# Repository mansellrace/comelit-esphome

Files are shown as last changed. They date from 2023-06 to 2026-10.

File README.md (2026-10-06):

# comelit-esphome
Comelit Simplebus Interface for Home Assistant

It works with simplebus 1, simplebus 1 color, simplebus 2.

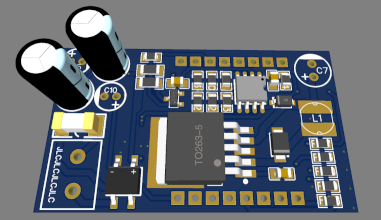
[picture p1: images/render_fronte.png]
render
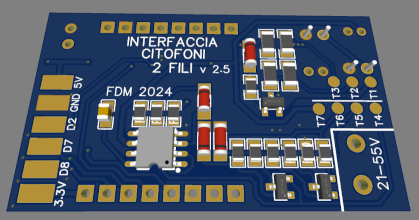
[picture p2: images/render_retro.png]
render2
 

**Side project:** *There is also a side-project that shares the same hardware: [comelit-esp8266](https://github.com/mansellrace/comelit-esp8266). it is a simplified and unrelated version of the home assistant world, created to allow decoding and interfacing the same protocol, with the same hardware, to interface the comelit bus even different home automation systems, to build intercom call repeaters, etc.*

## Introduction to the project
Initially, I wanted to modify my Comelit mini hands-free intercom 6721W to interface it with Home Assistant, so that I can receive a notification when someone intercoms me, and to be able to open the two doors controlled by the intercom conveniently remotely.

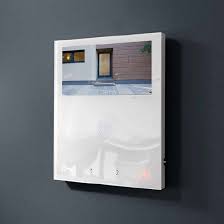
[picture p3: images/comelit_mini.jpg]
Comelit mini


The intercom works on Comelit's proprietary Simplebus2 2-wire bus.

I wanted to connect directly to the printed circuit board of the indoor station, which, however, uses the same speaker for ringing and voice calling, has touch buttons, the situation was getting complicated. I discarded the idea of using a Ring Intercom, because although it works very well and supports the Simplebus2 protocol, it does not allow you to control the opening of the second door, is bulky, works only in the cloud, and has the problem of battery power.

I then discovered the wonderful work of **[plusvic](https://github.com/plusvic/simplebus2-intercom)** who analyzed and decoded the simplebus protocol, and made a ring repeater based on a PIC used to decode the protocol, a wireless transmission chip and ESP8266. 
**[aoihaugen](https://github.com/aoihaugen/simplebus2-intercom)** created a fork, and adapted the code to decode the signal on arduino. I want to give a huge thanks to both of you, without your work I would never have reached my goal, I took abundant cues from both of you for hardware and software.

In my implementation I used a Wemos d1 mini with Esphome-based firmware for easy integration on Home Assistant. Can also interface with [Homey Pro](homey.md)

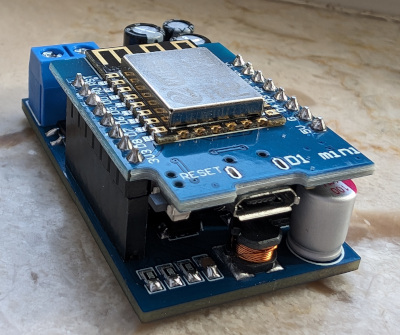
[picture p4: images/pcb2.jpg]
PCB2
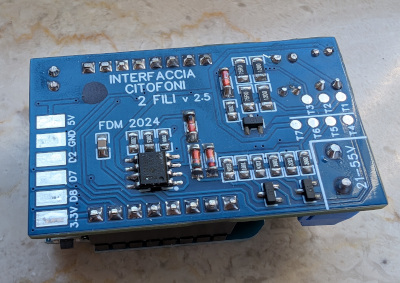
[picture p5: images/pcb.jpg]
PCB
 

The project makes it possible to receive and send commands that pass through the comelit bus, such as calling an internal intercom, opening a door, etc.

It is not possible to receive and send audio and video stream to home assistant.

You can receive a notification when someone sends a call to your internal intercom, and you can open the external door via home assistant.

You can send any command that the indoor intercom or the outdoor intercom generates.

The project supports switching of comelit expansion relays, allows control of multiple gates, separate triggers for call from external intercom or for out-of-door call, etc.

The pcb is powered directly from the bus, and is to be connected directly in parallel with the indoor intercom.

## Purchase materials and pcb

I can supply the printed circuit board, components, or even the entire hardware already soldered and tested.

If you are interested, please contact me at mansellrace@gmail.com

## [Protocol explanation](protocol.md)

## [Hardware and schematics](hardware.md)

## [External component docs](components/README.md)

## First set-up
Prerequisite: Home Assistant.

Boards supplied by me arrive already flashed. If you assembled your own, install the firmware from the [project page](https://mansellrace.github.io/comelit-esphome/) straight from your browser over USB.

- Connect the pcb to the bus. A wifi network called comelit-default will appear. Connect and open the browser, a page will pop up that allows you to set up your wifi network. If it does not open go [here](http://192.168.4.1)
- Home Assistant will discover the device automatically. Add it from the ESPHome integration. Among its entities you will find an **Intercom address** number, an **Incoming call** binary sensor and an **Open Door** button.
- Find your address: go [here](http://comelit-default.local/), where you will find a log of the commands received from the bus. Press a button on your intercom and note the address it generated.
- Set the **Intercom address** number to that address. The **Incoming call** sensor now fires whenever someone calls your intercom. The address is read at runtime, so there is nothing to recompile.
- The **Open Door** button sends command 16, which in most cases already opens the main gate.
- Firmware updates show up on their own as an update entity in Home Assistant. Press "Install" when one appears.
- Have fun!

Besides the binary sensor, every command received on the bus is also fired as a Home Assistant event, which you can use to trigger automations without adding any entity. [More information here](components/README.md#event)

## Doorbell notification on your phone

[@matzZz](https://github.com/matzZz) built a Home Assistant blueprint on top of this project: when someone rings, the phones you choose get a push notification with an **Open door** button.



- The door cannot be opened by accident: the button only shows up on a long press, a locked phone asks for Face ID or to be unlocked first, and the button works only for a limited time after the ring (2 minutes by default). Every ring gets its own button, so an old notification opens nothing.
- As soon as someone opens the door, or the time runs out, the notification disappears from every phone. Optionally, everyone gets a message saying who opened.
- It can notify only the phones that are at home.

It only needs two entities the device already has: choose **Incoming call** as the ring sensor and **Open Door** as the door opener.

Requirements: Home Assistant 2025.4 or later, and the Home Assistant Companion app on the phones. To notify only the phones that are at home, location tracking must be enabled in the app.

You can also install it by hand: copy [comelit_doorbell_door_opener.yaml](blueprints/automation/comelit_doorbell_door_opener.yaml) into the `blueprints/automation/` folder of your Home Assistant configuration.

## Customising your device

The stock firmware covers one intercom address and two doors. If you need more than that (several binary sensors, extra buttons, expansion relays, a different sensitivity), you can **adopt** the device:

- Install the "ESPHome Device Builder" add-on. It will show your device with an **ADOPT** button.
- Adopting copies the whole stock configuration into your dashboard, so every entity is there in front of you, ready to be renamed, removed or added to.
- Full list of options: [external component docs](components/README.md).

> [!IMPORTANT]
> Once you adopt the device, its configuration is yours and the automatic update entity goes away. From that point on you update it by recompiling from the ESPHome Device Builder.

## Commands description

An explanation of the commands that can be found on the bus can be found [here](protocol.md#list-of-commands)

## Updates:
- **2023, June**: First hardware revision and first available software
- **2023, August**: Hw version 2.0, first tests with onboard switching regulator, added pads to easily connect to some external pins
- **2023, September**: Hw version 2.2, added protection circuit for power section. Added dynamic resistor in series with power supply.
- **2023, November**: Hw version 2.4, minor adjustments to power section, added possibility of simultaneous bus and usb connection.
- **2023, November**: Thanks to [@monxas](https://github.com/monxas) for creating a box that can be 3d printed :)
- **2024, January**: Hw version 2.5, added ability to adjust reception sensitivity to two levels
- **2024, February**: Release of the new software. Now the project is based on an external component of esphome and configuration is much easier.
- **2024, August**: Hw version 2.6, added compatibility with simplebus 1 and simplebus 1 color. There is also a hardware revision dedicated to intercom kit systems with 2 wires for bus wires and 2 wires for power.
- **2025, April**: Hw version 2.7 specific for Simplebus 1
- **2025, August**: Software release 2025.08. Home Assistant events now require `homeassistant_services: true` inside the `api` configuration.
- **2026, August**: The address of a binary sensor can be a lambda, so it can be driven from a Home Assistant `number` entity and changed at runtime without recompiling anything.
- **2026, August**: Two new entities report what travels on the bus: a `text_sensor` showing the last command as `C50_A10`, and an `event` entity tied to one address that fires with the command number.
- **2026, August**: Boards now ship pre-flashed and keep themselves up to date. Each release is built and published automatically, a **Firmware** update entity shows the new version in Home Assistant, and the device can be adopted in the ESPHome Device Builder to get the whole configuration for editing. Esphome compiler is no longer required for most installations, and the setup is quicker. Blank boards can be flashed from the browser at the [project page](https://mansellrace.github.io/comelit-esphome/).
- **2026, September**: Thanks to [@matzZz](https://github.com/matzZz) for a Home Assistant blueprint that sends a push notification with an "Open door" button when someone rings. [Details here](#doorbell-notification-on-your-phone)
- **2026, October**: Thanks to Eladio for testing the board with Homey Pro. [Homey Pro quick guide](homey.md)

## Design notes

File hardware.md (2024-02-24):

# Hardware

I adapted the circuit proposed by plusvic by modifying it to fit the situation of my condominium system and the needs of esphome.
The open circuit voltage I detect on the bus wires is about 35V, and the data signal is superimposed on the DC voltage.

The exchange of information (commands) between indoor and outdoor station is through a 25kHz modulated data signal, in my case of peak-to-peak amplitude varying from 0.5V to 5V depending on the distance of the device that is transmitting.
When audio/video communication is initiated, an additional high-frequency signal is added.

render render2

[Schematic here](schematic_2.5.pdf)

## Power supply and filtering

The circuit has the option of being powered directly from the bus.

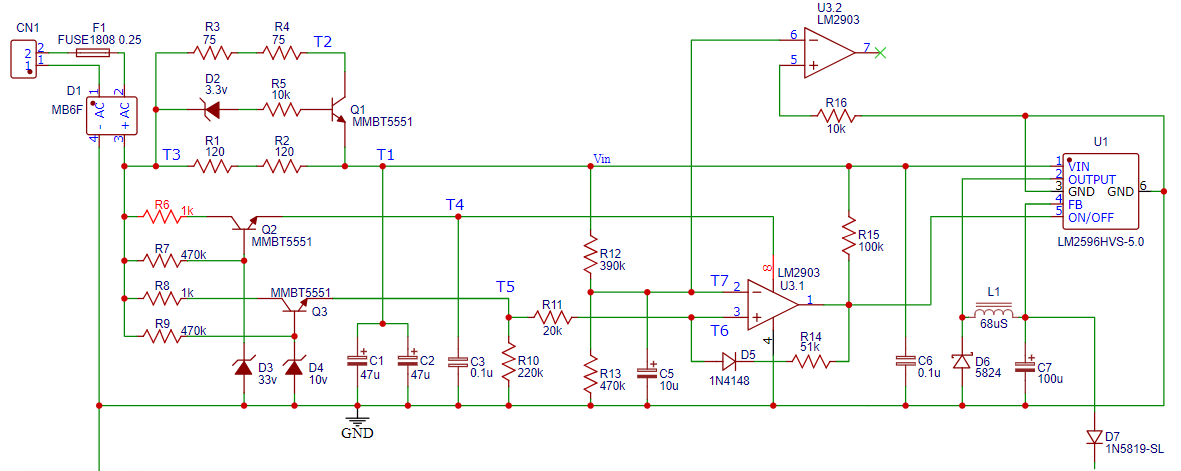
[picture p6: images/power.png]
power


I decided to use a wide-range input switching regulator, LM2596HVS-5.0, which supports up to 60v input and gives 5v output.

The whole circuit draws about 20mA from the bus line, which increases to 160mA during data transmission.

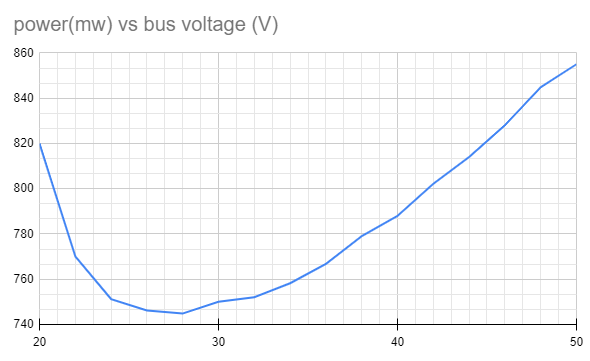
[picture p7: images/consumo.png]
consumo


I placed a 250mA fuse at the input to protect the circuit, followed by a rectifier bridge.

Power for the switching module is taken downstream from an RC low-pass filter, formed by R1, R2, R3, R4, and C1, C2, which eliminates fluctuations due to data transmission. 

Since the circuit must work well over a wide voltage range, the resistor value is "dynamic."
R1 and R2 are directly placed in series with the load.
When the voltage at the ends of R1 and R2 is greater than 2.5v, the resistor branch formed by R3 and R4 is gradually placed in parallel.
This causes the value of the overall resistance to vary linearly from 240Ω to 80Ω, adjusting automatically according to the current flowing through them.

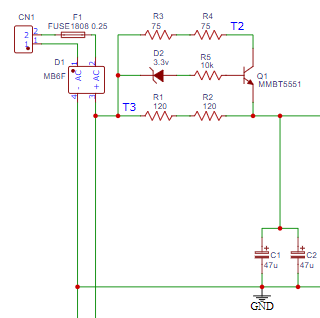
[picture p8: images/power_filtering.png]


### Power supply protection

The bus voltage may vary depending on the system.
Normal values for a video system are about 32-38v.
Some times they operate with voltages around 25v.

The switching regulator suffers from low bus voltages.
When the input voltage decreases, it requires more current from the bus to compensate.
But requiring more current generates more drop on the filter resistors, so the input voltage to the switching drops and the system collapses.
With wemos consumption, the situation becomes unstable below 18v from the bus.
 
In some intercom systems, after a power failure, the power supply slowly switches the bus on, so sometimes the voltage can be below 18v.
To protect the circuit, I added a protection stage that enables the switching regulator only under certain conditions.

The heart of this circuit is a comparator made with LM2903. It compares the voltage across the capacitors that feeding the switching ic with a reference obtained with zener stabilization. There is also a hysteresis. The circuit enables the switching ic when the input voltage is at least 20.5v and when it is stable for a few seconds.
After enabling it, the turn-off threshold is lowered by D5, R14 to about 18v.
In this way, the circuit never becomes unstable.

If the system works with low voltages (around 21-22v), more stability can be achieved by shorting R1.
In this case the shutdown threshold is lowered by a couple of volts and the system remains stable.

## Data receiving section

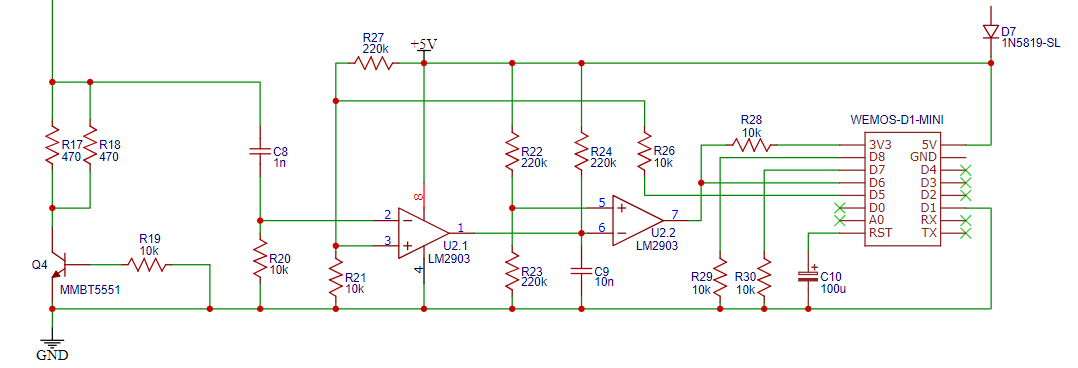
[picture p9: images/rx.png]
rx


As in the circuit I was inspired by, the data signal is picked up from the bus by a high-pass type filter, in the schematic consisting of R20 and C8, 10kΩ and 1nF, respectively.

The filter has a cutoff frequency of about 15kHz, sufficient to reduce interference due to baseband audio communication.

The signal at the ends of the resistor is then given as input to a dual LM2903 comparator with an open collector type output.

The threshold against which the signal is compared is variable, depending on how output D5 is set.
In this way the input sensitivity can be adjusted to two levels according to the plant situation; sometimes the bus may receive interference.

To simplify signal reception by the Wemos, I decided to insert a monostable stage, eliminating the 25-kHz carrier and taking advantage of the second comparator already on board the LM2903.

In the presence of a signal, the output of the first comparator is brought low by discharging the 10nF capacitor C9; in the absence of a signal, the capacitor is charged through the 220kΩ resistor R24.

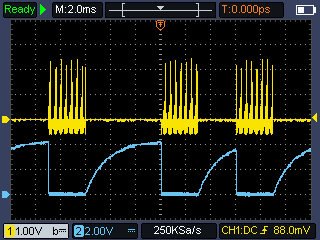
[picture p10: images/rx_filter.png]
rx_filter


The voltage at the capacitor is compared with a second fixed voltage obtained from the 5v.
The output of the second comparator is sent to the Wemos, which will then have data packets stripped of carrier oscillation as input.

In the presence of any input signal, the output of the second comparator remains high for an additional 1.5ms beyond the time the signal on the bus remains high.
A time of 20µs would have sufficed to demodulate the command carrier, but increasing the timing this much allowed me to reduce the pickup of additional signals present on the bus, which disrupt the reception and decoding of commands.

## Data transmission section

Data transmission is accomplished by creating a pulse absorption on the bus, modulated at 25kHz, with the timing dictated by the communication protocol.
A digital pin of the wemos drives an NPN transistor, which must support voltages of at least 40v and currents of at least 150mA.

The current flowing through the transistor is set by the value of the resistor placed on the collector.
I chose to connect two 470Ω resistors in parallel to divide the power dissipation.

With higher resistor values, the commands sent by the wemos are not always received correctly.

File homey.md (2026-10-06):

# Using the board with Homey Pro

The board does not need Home Assistant: Homey Pro talks to it directly over the ESPHome API.
This guide was tested on a Comelit 6741W monitor (Simplebus 2) with the stock pre-flashed firmware.
Thanks to Eladio for trying it out and sharing his setup.

## 1. Connect the board to your Wi-Fi

Same as in the [first set-up](README.md#first-set-up): connect the board to the bus, join the
`comelit-default` Wi-Fi network and enter your own network in the page that pops up.

Tip: reserve a fixed IP address for the board in your router, Homey connects to it by IP.

## 2. Set your intercom address

Homey does not show the **Intercom address** setting, so set it from the board's own web page:

- Open [http://comelit-default.local/](http://comelit-default.local/) (or the board's IP address).
- Press a button on your intercom: **Last command** and the log show it as `C<command>_A<address>`,
  for example `C16_A24`. The number after `A` is your address.
- Type that number into **Intercom address**. It is kept across reboots.

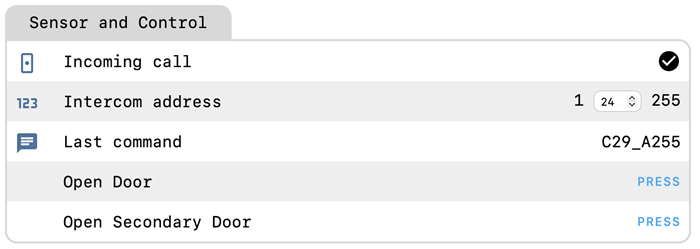
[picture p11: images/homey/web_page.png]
Board web page


Until the address is set, **Incoming call** never turns on.

## 3. Add the board to Homey

- Install the **ESPHome Controller** app. There are several ESPHome apps for Homey, this is the one
  that works.
- Add the device manually: enter the board's IP address and port `6053`, then scan its entities.

Homey shows four entities:

- **Incoming call**: turns on when someone calls your intercom, and off again after 30 seconds.
- **Open Door**: opens the main door.
- **Open Secondary Door**: opens the secondary door.
- **Last command**: the last command seen on the bus.

## 4. Create your flows

- **Doorbell notification**: use **Incoming call** turning on as the trigger, and send a push
  notification to the phones you want.
- **Open the doors**: press **Open Door** or **Open Secondary Door** from the device page in Homey,
  or use them as actions in a flow.

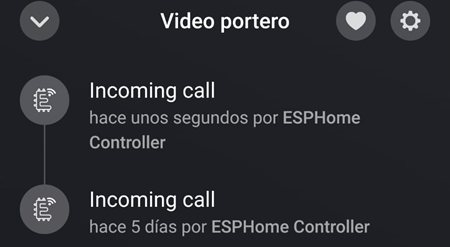
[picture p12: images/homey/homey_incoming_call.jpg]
Incoming call in Homey


Push notification

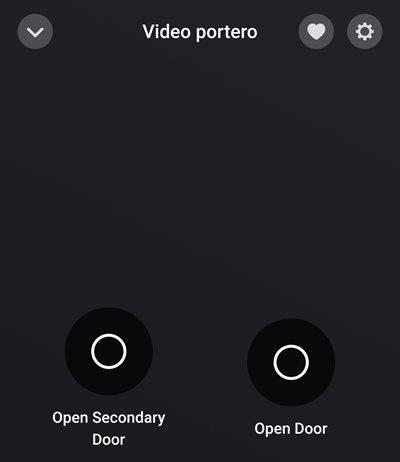
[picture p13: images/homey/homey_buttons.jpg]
Door buttons in Homey


## Troubleshooting

- **Incoming call never turns on**: the intercom address is not set, see [step 2](#2-set-your-intercom-address).
- **"Cannot send command: client not connected"** when pressing a door button: restart the
  ESPHome Controller app in Homey.
- **`Home Assistant event 'esphome.comelit' dropped`** warnings in the board's log: this is normal
  without Home Assistant and can be ignored.

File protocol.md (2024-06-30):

# Communication protocol

The exchange of information between the various devices takes place via a protocol based on a 25Khz carrier. Such a carrier is always sent for 3ms. The duration of "silence" between two transmissions determines the value of the transmitted bit; 3ms corresponds to "0," 6ms corresponds to "1."

The transmission always begins with a 3ms pulse, followed by a 16ms silence.

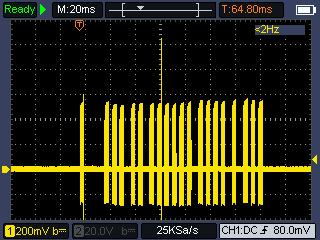
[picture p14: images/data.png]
data


Then 18 bits are sent, divided as follows:

The first 6 bits indicate the command, again starting with the least significant bit.

the next 8 bits indicate the address. The least significant bit is transmitted first.

the next 4 bits are checksum, they simply indicate the number of bits to 1 sent in the previous fields.

For example, when I call an indoor intercom from the door station, the command 50 is sent. Suppose we call intercom #21:

Command 50 = 110010
Address 21 = 00010101
Checksum 6 = 0110
The bit sequence sent is then 010011 10101000 0110

The decoding of the protocol was done by [plusvic](https://github.com/plusvic) and his explanation [can be found here](https://github.com/plusvic/simplebus2-intercom?tab=readme-ov-file#how-it-works)

Commands formatted in this way are then sent on the bus line to all internal and external intercoms.

A command is also sent when a request is made from the apartment station to activate video communication when there is no call (command 20), when the main door is commanded to open (command 16), when the secondary door is commanded to open (command 29), when an apartment station receives the "out of door" call, when audio conversation is initiated or interrupted, when the call goes into timeout, etc.

## List of commands

| Command | Description |
|---|---|
| 8 | Sent from intercoms to call the main switchboard |
| 9 | Sent from intercoms to call the caretaker phone (K) |
| 16 | Open building's entry door (AP). Sent when the intercom's open door button is pushed. Address tells who's opening the door |
| 17 | Sent when the user hooks off the intercom's handset |
| 18 | Sent when the user hooks on the intercom's handset. |
| 19 | Send from intercoms to call the secondary switchboard. |
| 20 | Turns on the video camera and the intercom's screen |
| 21 | Sent when the external switch connected to the CFP terminals is closed |
| 24 | Sent by one intercom to call other intercomms (INT) |
| 26 | After sending 24, three consecutive 26 is sent. |
| 29 | Activates a generic actuator. In some configurations used to turn on staircase lights, open secondary doors without intercom, open car gates |
| 30 | High prioritary call to main switchboard (PAN) |
| 32 | Sent from switchboard 1 for calling an intercom |
| 37 | Sent from switchboard 2 for calling an intercom |
| 42 | Sent from switchboard 3 for calling an intercom |
| 43 | Sent from switchboard 4 for calling an intercom |
| 45 | Sent from switchboard 5 for calling an intercom |
| 48 | Sent when someone calls at the building's entry in an audio only system |
| 50 | Sent when someone calls at the building's entry in a video system |
| 51 | Start blinking open door button |
| 52 | Stop blinking open door button |

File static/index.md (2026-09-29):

# About

An ESPHome firmware that connects a Comelit Simplebus 2 intercom to Home Assistant.
The board is powered from the 2-wire bus itself and taps it directly, so no extra wiring is needed.

Boards are shipped pre-flashed with this firmware. You only need the button below if you
are flashing a blank board yourself.

# Installation

You can use the button below to install the pre-built firmware directly to your device via USB from the browser.

<esp-web-install-button manifest="firmware/comelit-default.manifest.json"></esp-web-install-button>

<script type="module" src="https://unpkg.com/esp-web-tools@10/dist/web/install-button.js?module"></script>

# After installing

Connect to the `comelit-default` Wi-Fi network the device creates, enter your Wi-Fi
credentials in the captive portal, and Home Assistant will discover the device
automatically. Firmware updates then arrive on their own as an update entity.
Change the intercom address entity to match the address of your intercom, and the
binary sensor will go on when someone calls your intercom.

To get a notification on your phone with a button that opens the door, see the
[Home Assistant blueprint](https://github.com/mansellrace/comelit-esphome#doorbell-notification-on-your-phone).

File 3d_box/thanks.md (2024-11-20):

Thanks to [@monxas](https://github.com/monxas) for creating a box that can be 3d printed :)
Thanks to Gabry for creating the new version of the 3d box

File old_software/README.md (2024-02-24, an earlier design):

# comelit-esphome
Interfaccia Comelit Simplebus per Home Assistant

**Novità:** *Esiste anche un side-project che condivide lo stesso hardware: [comelit-esp8266](https://github.com/mansellrace/comelit-esp8266). è una versione semplificata e slegata dal mondo di home assistant, nata per permettere la decodifica e l'interfacciamento dello stesso protocollo, con lo stesso hardware, per interfacciare il bus comelit anche sistemi domotici diversi, per costruire ripetitori di chiamata citofonica, etc.*

## Introduzione al progetto

Inizialmente volevo modificare il mio citofono Comelit mini vivavoce 6721W per interfacciarlo ad Home Assistant, per poter ricevere una notifica quando qualcuno mi citofona, e per poter aprire i due portoni comandati dal citofono comodamente da remoto.

Comelit mini

Il citofono lavora su bus a 2 fili Simplebus2 proprietario di Comelit.
Volevo collegarmi direttamente al circuito stampato del posto interno, il quale però utilizza lo stesso altoparlante per la suoneria e per la chiamata vocale, ha pulsanti a sfioramento, la situazione si faceva complicata.
Ho scartato l’idea di usare un Ring Intercom, perché nonostante funziona benissimo e supporta il protocollo Simplebus2, non permette di comandare l’apertura del secondo portone, è ingombrante, lavora solamente in cloud e ha il problema dell’alimentazione a batteria.

Ho quindi scoperto il meraviglioso lavoro di **[plusvic](https://github.com/plusvic/simplebus2-intercom)** che ha analizzato e decodificato il protocollo simplebus, e ha realizzato un ripetitore di suoneria basato su un PIC usato per decodificare il protocollo, chip di trasmissione wireless, ESP8266.
**[aoihaugen](https://github.com/aoihaugen/simplebus2-intercom)** ha creato un fork, e ha adattato il codice per la decodifica del segnale su arduino.
Voglio fare un enorme ringraziamento ad entrambi, senza il vostro lavoro non sarei mai arrivato al mio obiettivo, ho preso abbondantemente spunto da entrambi per hardware e software.

Nella mia realizzazione ho utilizzato un Wemos d1 mini con firmware basato su Esphome, per una facile integrazione su Home Assistant.

## Hardware

Ho adattato il circuito proposto da **[plusvic](https://github.com/plusvic/simplebus2-intercom)** modificandolo per adattarlo alla situazione del mio impianto condominiale e alle necessità di esphome. La tensione a vuoto che rilevo sui fili del bus è di circa 35V, e il segnale dati è sovrapposto alla tensione DC. 
Lo scambio di informazioni (comandi) tra posto interno e posto esterno avviene attraverso un segnale dati modulato a 25kHz, nel mio caso di ampiezza picco-picco variabile da 0.5V a 5V in base alla distanza del dispositivo che sta trasmettendo. Quando viene avviata la comunicazione audio/video si aggiunge un ulteriore segnale ad alta frequenza.

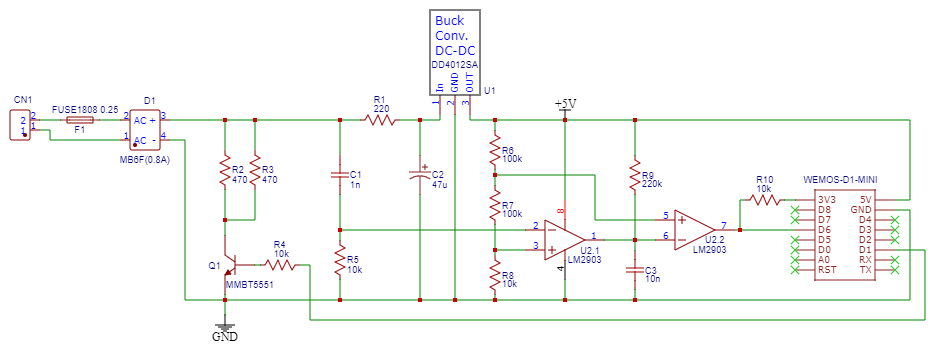
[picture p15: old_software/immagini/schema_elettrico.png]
Schema elettrico


### Sezione alimentazione

Il circuito ha la possibilità di essere alimentato direttamente dal bus.

Ho deciso di utilizzare un modulo switching step-down DD4012SA che supporta fino a 40v in ingresso e dà in uscita 5v.

L’intero circuito assorbe circa 20mA dalla linea bus, che salgono a 160mA durante la trasmissione dati.

Ho posto in ingresso un fusibile da 250mA a protezione del circuito, seguito da un ponte raddrizzatore.

L’alimentazione del modulo switching è presa a valle di un filtro RC passa basso, formato da R1 e C2, che elimina le fluttuazioni dovute alla trasmissione dati. Dopo diverse prove il miglior compromesso tra riduzione del rumore ricevuto e indotto sul bus e potenza dissipata l’ho ottenuto con una resistenza da 220Ω, che dissipa appena 75mW in maniera continuativa.

### Sezione ricezione dati

Come nel circuito a cui mi sono ispirato, il segnale dati viene captato dal bus grazie a un filtro di tipo passa alto, nello schema composto da R5 e C1, rispettivamente da 10kΩ e 1nF. 

Il filtro ha una frequenza di taglio di circa 15kHz, sufficienti a ridurre le interferenze dovute alla comunicazione audio in banda base.

Il segnale ai capi della resistenza viene quindi dato in ingresso ad un doppio comparatore LM2903 con uscita di tipo open collector. La soglia con cui viene comparato il segnale è posta a circa 0.25v tramite un partitore resistivo.

Per semplificare la ricezione del segnale da parte del Wemos ho deciso di inserire uno stadio monostabile, eliminando la portante a 25 kHz e sfruttando il secondo comparatore già a bordo dell’LM2903.

In presenza di segnale, l’uscita del primo comparatore viene portata bassa scaricando il condensatore C3 da 10nF, in mancanza di segnale il condensatore si carica attraverso la resistenza R9 da 220kΩ.

La tensione ai capi del condensatore viene comparata con una seconda tensione fissa, ricavata dallo stesso partitore usato sul primo stadio. L’uscita del secondo comparatore viene mandata al Wemos, che quindi si ritroverà in ingresso i pacchetti dati privati dell’oscillazione della portante.

In presenza di un qualsiasi segnale in ingresso, l’uscita del secondo comparatore rimane alta per ulteriori 1.5ms oltre al tempo in cui il segnale sul bus resta alto. Per demodulare la portante dei comandi sarebbe bastato un tempo di 20µs, ma aumentare così tanto la tempistica mi ha permesso di ridurre la captazione di ulteriori segnali presenti sul bus, che disturbano la ricezione e la decodifica dei comandi.

### Sezione trasmissione dati

La trasmissione dati avviene creando un assorbimento impulsivo sul bus, modulato a 25kHz, con le tempistiche dettate dal protocollo di comunicazione. Un piedino digitale del wemos pilota un transistor NPN, che deve supportare tensioni di almeno 40v e correnti di almeno 150mA. Nel prototipo che ho realizzato ho utilizzato un BC337. 

La corrente che passa dal transistor viene imposta dal valore della resistenza posta sul collettore. Ho scelto di collegare due resistenze da 470Ω in parallelo per dividere la dissipazione di potenza. 

Nel mio caso, con valori resistivi più alti, i comandi inviati dal wemos non sempre vengono ricevuti correttamente. In base alla distanza dall’alimentatore del bus potrebbe essere necessario modificare il valore.

### Realizzazione Hardware

Inizialmente ho realizzato il circuito su breadboard, una volta messo a punto lo schema definitivo ho realizzato un pcb utilizzando componenti in tecnologia SMD, grande appena 46 x 29 mm, ovvero poco più grande del wemos D1 mini. Nel mio caso è entrato perfettamente dentro la scatoletta tonda predisposta dietro al citofono.

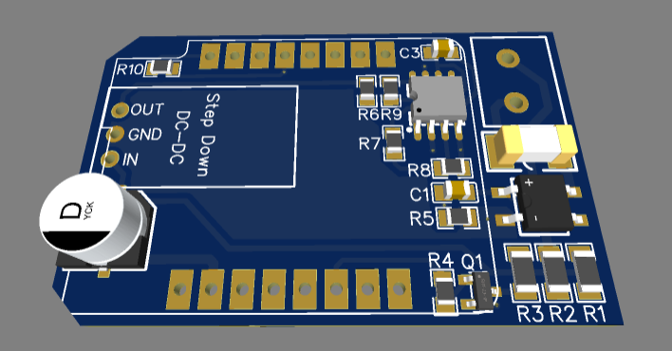
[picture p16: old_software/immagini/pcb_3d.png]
pcb_3d
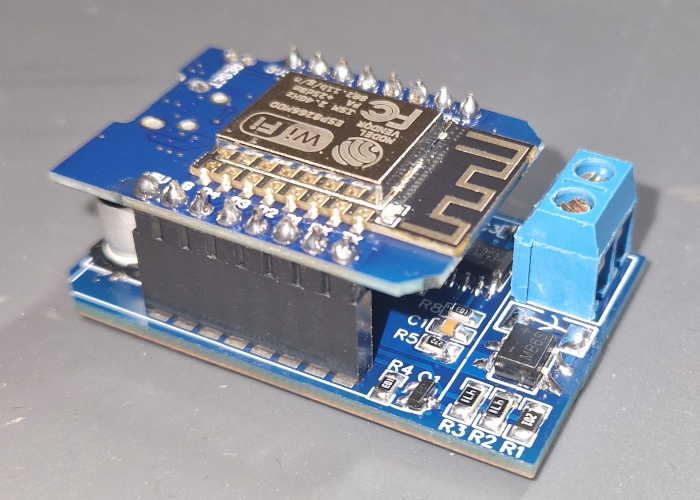
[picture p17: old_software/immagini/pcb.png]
pcb
 

Se l’impianto citofonico è alimentato dal contatore condominiale potreste decidere di non alimentare il wemos dal bus, non montando il modulo switching e alimentando il wemos a 5v in maniera indipendente. In tale maniera il consumo del wemos (0.5w) non graverà sull’alimentazione elettrica condominiale

## Protocollo

Come già accennato, lo scambio di informazioni tra i vari dispositivi avviene tramite un protocollo basato su una portante a 25Khz. Tale portante viene sempre inviata per 3ms. La durata del “silenzio” tra due trasmissioni determina il valore del bit trasmesso, 3ms corrisponde a “0”, 6ms corrisponde a “1”.

La trasmissione inizia sempre con un impulso da 3ms, seguito da un silenzio di 16ms.

Successivamente vengono inviati 18 bit, così suddivisi:

- i primi 8 bit indicano l’indirizzo. Viene trasmesso per prima il bit meno significativo.
- i successivi 6 bit indicano il comando, anche qui si parte dal bit meno significativo.
- i successivi 4 bit sono di checksum, indicano semplicemente il numero di bit a 1 inviati nei campi precedenti.

Ad esempio, quando dal posto esterno chiamo un citofono interno viene inviato il comando 50. Supponiamo di chiamare il citofono n°21:
- Comando 50 = 110010
- Indirizzo 21 = 00010101
- Checksum 6 = 0110

La sequenza di bit inviata è quindi 010011 10101000 0110

Sulla linea bus vengono quindi inviati comandi così formattati a tutti i posti interni.

Viene inviato un comando anche quando dal posto interno si richiede di attivare la comunicazione video in assenza di chiamata (comando 20), quando si comanda l’apertura del portone principale (comando 16), quando si comanda l’apertura del portone secondario (comando 29), quando un posto interno riceve la chiamata “fuori porta”, quando si avvia o si interrompe la conversazione audio, quando la chiamata va in timeout, etc.

## Software

Come piattaforma software ho usato ESPhome per una veloce integrazione su home assistant.
Ho deciso di sfruttare i componenti *“remote receiver”* e *“remote transmitter”* per la decodifica dei bit ricevuti. 

Remote receiver decodifica automaticamente i protocolli più comuni relativi a telecomandi o trasmettitori radio. 

Se la decodifica nativa non è disponibile, si può ricorrere alla modalità raw: ogni volta che viene ricevuto un treno di impulsi viene eseguita una automazione a cui viene passato un array di numeri interi. Il primo numero dell’array, positivo, indica per quanti microsecondi il segnale in ingresso è stato a valore logico alto. Il secondo valore, negativo, indica quanti microsecondi il segnale in ingresso è stato a valore logico basso. I successivi valori seguono la stessa logica, alternando sempre numeri positivi e negativi.

Viene da sé che basta controllare il valore dei numeri negativi dell’array per decodificare il comando e l’indirizzo del protocollo comelit simplebus2.

L’automazione dapprima controlla se la lunghezza dell’array è quella che ci aspettiamo per un comando correttamente ricevuto, quindi viene decodificato il valore dell’indirizzo e del comando, viene eseguito il controllo del checksum, e se il checksum è corretto viene generato un evento di home assistant del tipo “esphome.comelit_ricevuto” con comando e indirizzo nel campo dati.

Basterà creare una automazione su home assistant triggerata dall’evento, discriminando solamente quelle con comando “50” e indirizzo relativo al proprio posto interno, per poter ricevere una notifica quando viene chiamato il nostro citofono.

#### esempio di trigger:

    platform: event
    event_type: esphome.comelit_ricevuto
    event_data:
      comando: "50"
      indirizzo: "11"

Per poter inviare i comandi sul bus, ho realizzato una semplice funzione che viene richiamata tramite un servizio di Home Assistant, la quale converte i campi indirizzo e comando nell’array di interi che può essere dato in pasto al componente “remote transmitter”.
Remote transmitter si occuperà di pilotare il transistor, modulandolo con una portante a 25kHz per il numero di microsecondi indicato nei valori interi dell’array.

La funzione che si occupa della codifica risiede all’interno del file comelit.h, che deve essere inserito nella cartella “esphome” della propria configurazione di home assistant, verrà richiamata tramite un include.

Si possono realizzare anche servizi con già codificati all’interno comando e indirizzo fissati precedentemente. Si potrà creare quindi un comodo widget sul proprio smartphone, il quale richiamerà semplicemente il servizio “esphome.apri_portone” per poter aprire il portone con un tocco.

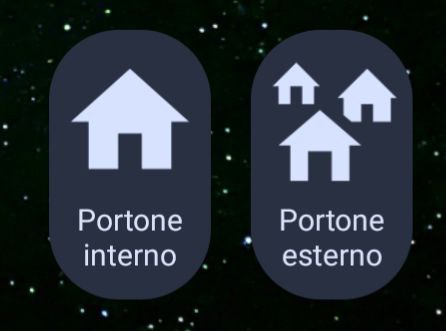
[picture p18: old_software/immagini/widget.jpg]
Widget


Il sistema crea un evento sul log di home assistant per ogni comando ricevuto sul bus. Se non si vuole utilizzare questa funzione basta eliminare la parte di software relativa.

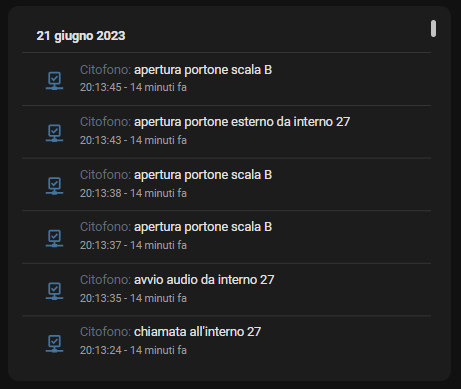
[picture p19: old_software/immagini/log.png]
Log


Il log viene "agganciato" all'entità sensor.comelit_stato

## Installazione

- Copiare dentro la cartella esphome di home assistant il file comelit.h
- Collegare il wemos al pc e aggiungerlo alla propria configurazione di esphome. Non collegarlo al pc mentre che è alimentato dal bus.
- Appuntarsi la api encription key e la ota password del file di configurazione generato automaticamente.
- Sostituire il codice base generato da esphome col codice del file esphome.yaml
- Sostituire la api encription key e la ota password appuntati precedentemente negli appositi campi.

## Acquisto materiali e pcb

Ho la possibilità di fornire il pcb, i componenti, o anche l'intero hardware già saldato e collaudato.

Se sei interessato, contattami su mansellrace@gmail.com

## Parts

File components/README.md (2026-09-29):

Comelit Intercom component
===================

> [!IMPORTANT]
> ### **Please note**:
>
> for new features introduced in version 2025.08, you need to add the line "homeassistant_services: true"
>
> inside the api configuration, like this
>
>      api:
>        homeassistant_services: true

The ``comelit_intercom`` allows you to easily interface the esphome-comelit project on esphome and home assistant

Basic esphome configuration entry:

    external_components:
      - source: github://mansellrace/comelit-esphome

    comelit_intercom:

Example of a configuration entry, which generates a binary_sensor entity that goes to on when receiving a call to internal intercom 10, and a button entity that when pressed sends the command to open external door

    external_components:
      - source: github://mansellrace/comelit-esphome
      
    comelit_intercom:
    
	binary_sensor:
	  - platform: comelit_intercom
	    address: 10
	button:
	  - platform: template
	    name: Open Door
	    on_press:
	      - comelit_intercom.send:
	          command: 16
	          address: 10

A complete, working example is the configuration the boards ship with: [comelit-default.yaml](../comelit-default.yaml)

Configuration variables:
------------------------

- **hw_version** (*Optional*, string): The hardware version of the pcb. One of ``older``, ``2.5`` or ``2.6``. Defaults to ``2.5``.
- **sensitivity** (*Optional*, string): The level of receiving sensitivity.
  - For hardware version 2.6, from ``1`` to ``9``. Defaults to ``8``.
  - For hardware version 2.5, the allowed values are ``high`` and ``low``. Defaults to ``high``.
  - For older hardware version, it is not possible to change the sensitivity.
- **rx_pin** (*Optional*, pin): The pin used to receive commands. Defaults to ``D6``.
- **tx_pin** (*Optional*, pin): The pin used to transmitt commands. Defaults to ``D1``.
- **filter** (_Optional_,  [Time](https://esphome.io/guides/configuration-types#config-time)): Filter any pulses that are shorter than this. Useful for removing glitches from noisy signals. Defaults to `1000us`, maximum `2500us`.
-   **idle**  (_Optional_,  [Time](https://esphome.io/guides/configuration-types#config-time)): The amount of time that a signal should remain stable (i.e. not change) for it to be considered complete. Defaults to  `10ms`.
-   **buffer_size**  (_Optional_, int): The size of the internal buffer for storing the remote codes. Defaults to  `400b`.
-  **dump** (_Optional_, bool): If set to on, the timing of received signals is printed on the log. Useful for debugging. If you also set the logger to "VERBOSE" you will also see the raw data received. Defaults to  `false`.
- <a id="eventlist">**event**</a>  (_Optional_, string): The name of the event that will be generated on home assistant when receiving a command from the bus. For example, if  set to `comelit`, the event generated will be "esphome.comelit".
Read more about how to use it in the [Home Assistant event section](#home-assistant-event)
Default to `comelit`.
If this parameter is set to `none` no event will be generated.

Binary sensor
===================

You can configure binary sensors that go on when a particular combination of command and address is received from the bus.

You can also set only the address, in this case the default command is 50, which occurs when a call is made from the outside intercom to the inside intercom.

Configuration examples:

	binary_sensor:
	  - platform: comelit_intercom
	    address: 16
	  - platform: comelit_intercom
	    command: 29
	    address: 1
	    name: Internal Door opened
	    auto_off: 60s

- **address** (**Required**, int, [templatable](https://esphome.io/automations/templates)): The address that when received sets the sensor to on. It is re-evaluated every time a command is received from the bus, so a lambda can be used to change the address at runtime without recompiling.
- **command** (*Optional*, int): The command that when received sets the sensor to on . Defaults to  `50`.
- **auto_off** (*Optional*,  [Time](https://esphome.io/guides/configuration-types#config-time)):  The time after which the sensor returns to off. If set to `0s` the sensor once it goes on, it stays there until it is turned off by an automation. Defaults to  `30s`.
- **icon** (*Optional*, icon): Manually set the icon to use for the sensor in the frontend. Default to `mdi:doorbell`.
- **id** (*Optional*, string): Manually specify the ID for code generation.
- **name** (*Optional*, string): The name for the sensor. Default to `Incoming call`.

    Note:
    If you have friendly_name set for your device and you want 
    the sensor to use that name, you can set `name: None`.

Text sensor
===================

A text sensor that shows the last command seen on the bus, as `C<command>_A<address>`. A call from
the entrance to intercom 10 (command 50) sets it to `C50_A10`.

Configuration examples:

	text_sensor:
	  - platform: comelit_intercom
	    name: Doors
	    commands: [16, 29]
	    addresses: [1, 10]
	    auto_clear: 0s

- **commands** (*Optional*, list of int): Only report these commands. If not set, every command is reported.
- **addresses** (*Optional*, list of int): Only report these addresses. If not set, every address is reported.
- **auto_clear** (*Optional*, [Time](https://esphome.io/guides/configuration-types#config-time)): The time after which the sensor goes back to an empty string. If set to `0s` the last command stays displayed until the next one arrives. Defaults to `10s`.
- **icon** (*Optional*, icon): Manually set the icon to use for the sensor in the frontend. Default to `mdi:message-text`.
- **id** (*Optional*, string): Manually specify the ID for code generation.
- **name** (*Optional*, string): The name for the sensor. Default to `Last command`.

    Note:
    Home Assistant only registers a state change when the state really changes. Two identical
    commands in a row (somebody ringing twice) are therefore a single state change, and an
    automation triggered on the state fires only once. `auto_clear` works around this by putting an
    empty string in between. If you need something that always fires, use the event entity below.

Event entity
===================

An [event entity](https://esphome.io/components/event/) tied to one address: every command
addressed to it fires the entity, and the event type is the command number. Unlike the text sensor,
an event always fires, even when the same command arrives twice in a row.

Configuration examples:

	event:
	  - platform: comelit_intercom
	    address: 10
	  - platform: comelit_intercom
	    name: Doorbell
	    address: 10
	    commands: [48, 50]
	    device_class: doorbell

- **address** (**Required**, int, [templatable](https://esphome.io/automations/templates)): The address this entity reports. It is re-evaluated every time a command is received from the bus, so a lambda can be used to change the address at runtime without recompiling, exactly like the binary sensor.
- **commands** (*Optional*, list of int): The commands this entity reports. If not set, every command is reported.
- **device_class** (*Optional*, string): One of `button`, `doorbell` or `motion`.
- **id** (*Optional*, string): Manually specify the ID for code generation.
- **name** (*Optional*, string): The name for the entity. Default to `Intercom event`.

The event type is the plain command number, so a call from the entrance in a video system
(command 50) fires the event type `50`. The meaning of each number is listed in
[protocol.md](../protocol.md#list-of-commands).

An event entity has to declare every event type it can ever report when the firmware is compiled.
That is why the address is a property of the entity instead of a part of the event type: it keeps
that list down to 63 entries at most, and it is what allows `address` to be a lambda.

In Home Assistant, trigger on the entity itself and read the command in a condition. Triggering
directly on the `event_type` attribute would miss the same command being received twice in a row.

	triggers:
	  - trigger: state
	    entity_id: event.intercom_event
	conditions:
	  - condition: state
	    entity_id: event.intercom_event
	    attribute: event_type
	    state: "50"

Home Assistant event
========
This is the `event:` option of `comelit_intercom`, not the `event` entity described above.

If the [event](#eventlist) parameter is not set to `none`, an event will be generated each time a command is received.

You can intercept events on home assistant on the page "developer tools -> event"

Each time a command is received, an event like this will be generated:

	event_type: esphome.comelit
	data:
	  device_id: xxxxxxxxxxxxxxxxxxxxxxxxx
	  address: "13"
	  command: "50"
	origin: LOCAL
	time_fired: "2024-01-01T00:00:00.000000+00:00"
	context:
	  id: xxxxxxxxxxxxxxxxxxxxxxxx
	  parent_id: null
	  user_id: null

To intercept this event to trigger an home assistant automation, you can use a trigger of type "event."

The trigger configuration will look like this:

	trigger: event
	event_type: esphome.comelit
	event_data:
	  command: "50"
	  address: "13"
You have to change the address and the name of the event you have chosen, if you have set a different one.

Transmit a command
==================
To send commands to the bus, the following action is available:

	- comelit_intercom.send:
	    command: 16
	    address: 1

- **command** (**Required**, int)
- **address** (**Required**, int)

### Button:
The action can be easily inserted into a button type entity:

	button:
	  - platform: template
	    name: Open Door
	    on_press:
	      - comelit_intercom.send:
	          command: 16
	          address: 5

### Service:
You can create a home assistant service, which can easily be invoked by an automation or script:

	api:
	  encryption:
	    key: "xxxxxxxxxxxxxxxxxxx"
	  services:
	    - service: open_door
	      then:
	        - comelit_intercom.send:
	            command: 16
	            address: 5

### Sending multiple commands:
There are some special configurations that require sending 2 or more commands consecutively on the bus.
In this case, a delay of at least 200ms must be inserted between the commands (one command takes about 180ms to be sent)

	- comelit_intercom.send:
	    command: 29
	    address: 1
	- delay: 200ms
	- comelit_intercom.send:
	    command: 16
	    address: 1

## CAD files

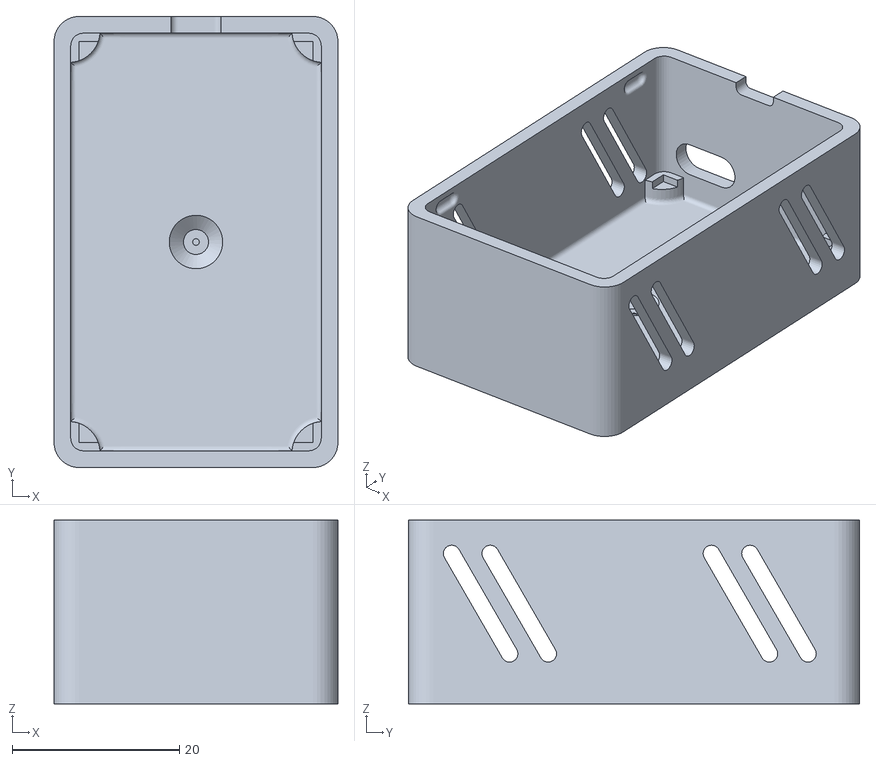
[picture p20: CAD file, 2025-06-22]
3d_box/Comelit box v3.stl
34.0 x 54.0 x 22.0

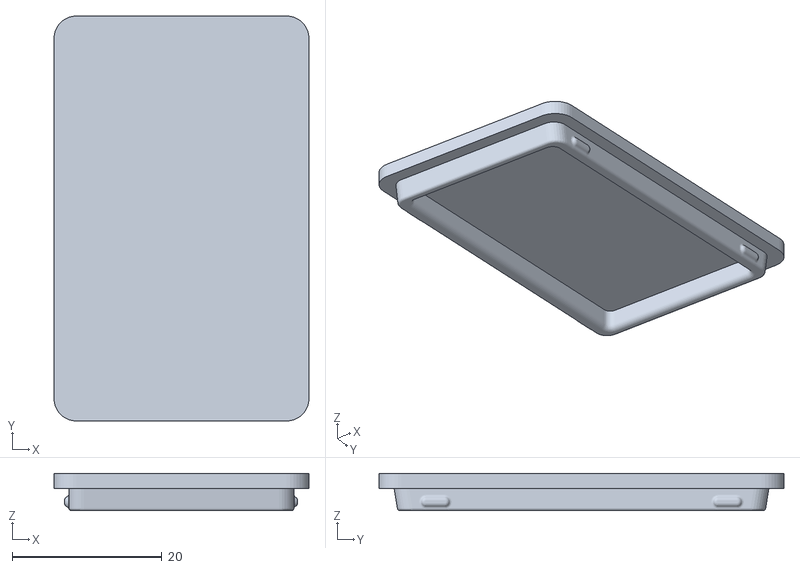
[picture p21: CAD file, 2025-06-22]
3d_box/Comelit top v3.stl
34.0 x 54.0 x 5.00

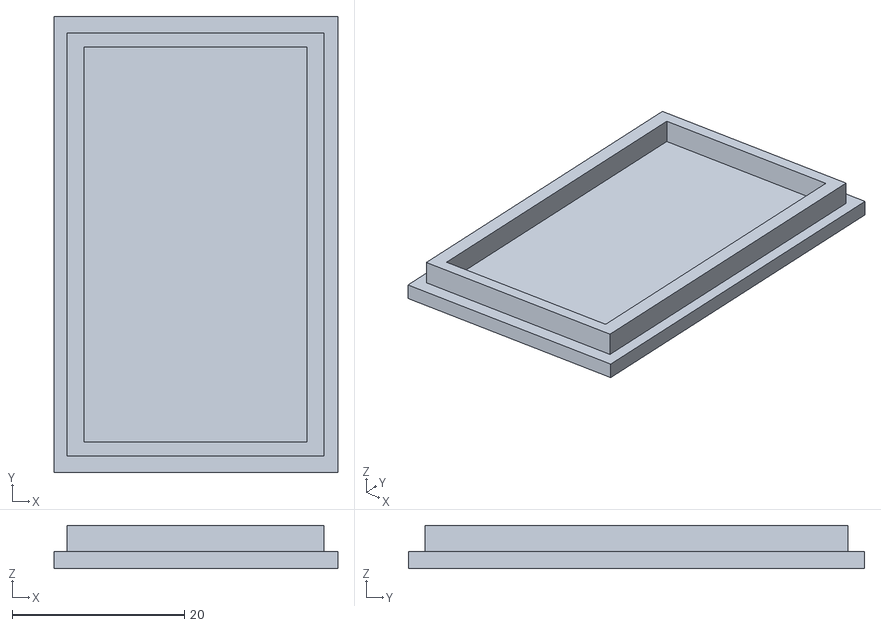
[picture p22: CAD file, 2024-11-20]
3d_box/top comelit v2.stl
33.0 x 53.0 x 5.00

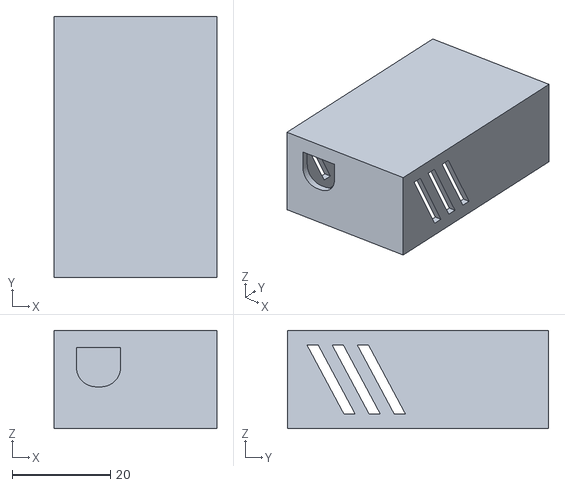
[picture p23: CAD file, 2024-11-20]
3d_box/box comelit v2.stl
33.0 x 53.0 x 20.0

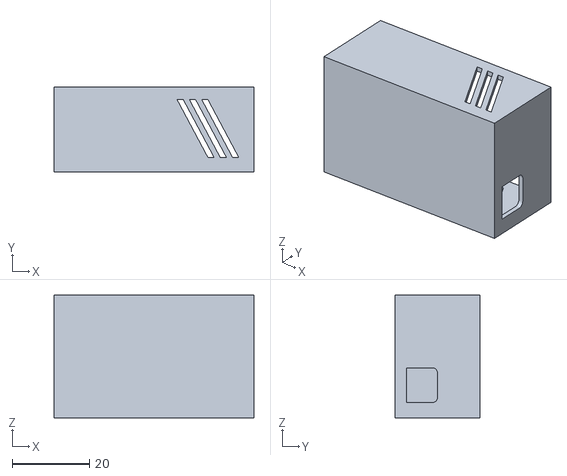
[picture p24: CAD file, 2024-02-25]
3d_box/comelit-box.stl
51.9 x 22.0 x 31.9

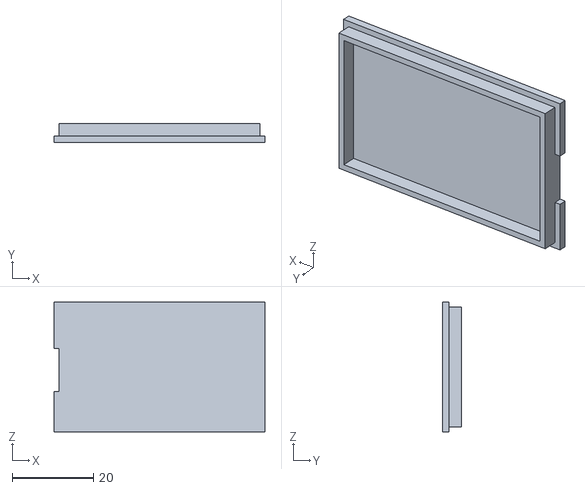
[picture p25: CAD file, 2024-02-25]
3d_box/comelit-top.stl
51.9 x 4.60 x 31.9

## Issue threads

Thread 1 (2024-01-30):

Installation error

Elektroarzt, 2024-01-30:
Hi mansellrace ... I'm trying to port your YAML code to ESP32. I did the following:
- changed ESP8266 platform to ESP32
- changed ESP8266 pins to the corresponding on ESP32 I used
- stored comelit.h in /homeassistant/esphome/

Validation is without errors. On attempt to upload I get errors you can see in the attached log file.
Do you have any idea to fix this?

[logs_esphome-web-381c28_run.txt](https://github.com/mansellrace/comelit-esphome/files/14099411/logs_esphome-web-381c28_run.txt)
[esphome-web-381c28.yaml.txt](https://github.com/mansellrace/comelit-esphome/files/14099426/esphome-web-381c28.yaml.txt)

mansellrace, 2024-02-08:
Hi,
The project has progressed from the version currently available on github. Both as hardware and software.

As hardware I created a new hardware version with a completely new power section, adding protections regarding undervoltages and instabilities that could occur.

As software I have in development an external component for esphome that will be more powerful, more customizable, easier to set up. is in good progress, the receiving part works well and I am refining some small details, I need to develop the transmission part , but I think it will take a short time.

I think in a week there will be big changes on this project, stay tuned!

Elektroarzt, 2024-02-08:
Super cool ... sounds good!

mansellrace, 2024-02-24:
Hi! New software and schematics is online! You can test it and if you have other problems you can open another issue or contact me on mansellrace@gmail.com

Closed 2024-02-24.

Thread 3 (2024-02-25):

Compatibility with ELVOX 7558

vekexasia, 2024-02-25:
Ciao,

Congrats on the project. looks good.
I'm currently using the ring intercom to have some kind of smart functionality on my own elvox 7558 intercom.

I never was able to find which kind of protocol it does use I was able to find [this manual](https://www.vimar.com/irj/go/km/docs/z_catalogo/DOCUMENT/49401463C0_MU_EN_01_7558.95533.pdf) but it does not seem to say much more than 2-wire-"plus"-bus?

mansellrace, 2024-02-25:
> I never was able to find which kind of protocol it does use I was able to find [this manual](https://www.vimar.com/irj/go/km/docs/z_catalogo/DOCUMENT/49401463C0_MU_EN_01_7558.95533.pdf) but it does not seem to say much more than 2-wire-"plus"-bus?

Hi, there aren't many specifications available about that bus.
I found that it works with 27v power and my board is compatible. Consumption is also compatible with that required.

To understand more, it would be necessary that someone who has this intercom system does some tests to understand what goes through that bus and try to decode the protocol.The reception part of my project should be compatible, unless you have to change some components. The decoding part of the protocol should be done from scratch.

mansellrace, 2024-02-25:
> I never was able to find which kind of protocol it does use I was able to find [this manual](https://www.vimar.com/irj/go/km/docs/z_catalogo/DOCUMENT/49401463C0_MU_EN_01_7558.95533.pdf) but it does not seem to say much more than 2-wire-"plus"-bus?

Hi, there aren't many specifications available about that bus.
I found that it works with 27v power and my board is compatible. Consumption is also compatible with that required.

To understand more, it would be necessary that someone who has this intercom system does some tests to understand what goes through that bus and try to decode the protocol.The reception part of my project should be compatible, unless you have to change some components. The decoding part of the protocol should be done from scratch.

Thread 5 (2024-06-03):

Error when compiling

danielfett, 2024-06-03:
I tried with ESPHome versions 2023.11.6 to the latest and always received the following error when compiling:

```
INFO ESPHome 2024.5.4
INFO Reading configuration dooresp.yaml...
INFO Generating C++ source...
INFO Compiling app...
Processing dooresp (board: d1_mini; framework: arduino; platform: platformio/espressif8266@4.2.1)
--------------------------------------------------------------------------------------------------------------------------------------------------------------------------------------------------------------------------------------------------------------------------------------------------------------------------------------------
HARDWARE: ESP8266 80MHz, 80KB RAM, 4MB Flash
Dependency Graph
|-- ESPAsyncTCP-esphome @ 2.0.0
|-- ESPAsyncWebServer-esphome @ 3.2.2
|-- DNSServer @ 1.1.1
|-- ESP8266WiFi @ 1.0
|-- ESP8266mDNS @ 1.2
|-- AsyncMqttClient-esphome @ 2.0.0
|-- ArduinoJson @ 6.18.5
Compiling .pioenvs/dooresp/src/esphome/components/comelit_intercom/comelit_intercom.cpp.o
src/esphome/components/comelit_intercom/comelit_intercom.cpp:3:10: fatal error: esphome/components/api/custom_api_device.h: No such file or directory
    3 | #include "esphome/components/api/custom_api_device.h"
      |          ^~~~~~~~~~~~~~~~~~~~~~~~~~~~~~~~~~~~~~~~~~~~
compilation terminated.
*** [.pioenvs/dooresp/src/esphome/components/comelit_intercom/comelit_intercom.cpp.o] Error 1
```

It seems that the respective file is not included in the files prepared for compilation. I ran esphome via pipx: `pipx run esphome compile dooresp.yaml`. I tried including comelit-esphome as a GIT dependency and downloaded it locally.

I was able to compile when commenting out the respective dependency and the lines using it.

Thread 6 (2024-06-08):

Timing issue when sending commands

danielfett, 2024-06-08:
I encountered problems when I tried to send commands while I had a number of (unrelated) components enabled. In my case, a bunch of buttons and sensors, nothing unusual and no other third-party components. It turns out that the current comelit-esphome protocol implementation only works well if there are no other components that delay the main loop. For debugging, I enabled the main loop timer debug of esphome.

```
[22:14:06][D][sensor:093]: 'Loop Time': Sending state 10.00000 ms with 0 decimals of accuracy
[22:14:11][D][sensor:093]: 'Loop Time': Sending state 7.00000 ms with 0 decimals of accuracy
[22:14:16][D][sensor:093]: 'Loop Time': Sending state 8.00000 ms with 0 decimals of accuracy
[22:14:21][D][sensor:093]: 'Loop Time': Sending state 7.00000 ms with 0 decimals of accuracy
[22:14:27][D][sensor:093]: 'Loop Time': Sending state 9.00000 ms with 0 decimals of accuracy
```

When the loop time is below ~7ms, everything works. Above that, the sending is unreliable or doesn't work at all.

I checked the code and it seems that the problem is that the control is handled back to the main loop to ensure that other components can do their thing while comelit-esphome waits before sending the next bits.

I was able to confirm that this is the problem by modifying ComelitComponent::loop() to the following:

```c
void ComelitComponent::loop() {
  while (this->sending){
    sending_loop();
  }
  ... (rest of the function as before) ...
```

While this ensures that the protocol timing works, it also means that other components have to wait too long before it's their turn to do something. This is confirmed by the following warning by esphome when the code is modified as shown above:

```
[22:14:01][W][component:237]: Component comelit_intercom took a long time for an operation (142 ms).
[22:14:01][W][component:238]: Components should block for at most 30 ms.
```

I would recommend to either try to predict the timing of the main loop and take that into consideration, or, if possible, to delegate sending to a separate thread.

mansellrace, 2025-08-25:
Hi Daniel,
Comelit has fairly strict tolerances on transmission times. The Wemos8266 cannot generate software PWM, and Comelit requires 25 kHz modulation, which is too much to be performed accurately without blocking the main loop.
I therefore decided to block the loop only during the transmission of each individual positive bit, leaving space for other tasks between one positive bit and the next (3 or 6 ms rest).

If you start to have a complex configuration, you can try to lighten it by disabling events
comelit_intercom:
  - event: none

or by using only events to achieve your goal, removing the sensors.

If you want, you can send me your yaml configuration so we can optimise it together.

Closed 2025-08-25.

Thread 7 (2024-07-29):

Comelit simplebus1 protocol

giuppi, 2024-07-29:
Ciao, great work!
My intercom uses Comelit simplebus1 protocol.
There's some work done by vvigilante https://github.com/vvigilante/comelit-simplebus1 to make it "smart".

Any chance your board could work with it? Thanks

mansellrace, 2024-07-29:
Ciao giuppi!

As for the software, there is a development branch on this project that will be moved to Main in the next few days. It manages to perform simplebus 1 reading and decoding without problems

The transmission software part has also been implemented. I had to add an additional dedicated transmission stage to allow for much more energetic transmission that the Simplebus 1 requires.

The problem of the simplebus 1 is the power supply: during data transmission the bus is almost shorted and there is not enough residual power to power the wemos, for this reason the Simplebus 1 may need external power.

I have developed a new hardware version 2.6 which includes the new transmission section for SimpleBus 1, and a reception section with 9 selectable sensitivity levels, to allow the circuit to adapt to the various cases.

There is also a new pcb suitable for Simplebus 1 4-wire door phone kits (two for bus and two for 24V power supply)

In the next few days I will upload the updated documentation. Meanwhile, the first V2.6 PCBs are already under construction

giuppi, 2024-07-30:
Great news!
Thank for the detailed update.

morschers, 2025-01-12:
Hello, and thank's for the project. In the github the diagram is still version 2.5. Can you update the 2.6 version?
Thx

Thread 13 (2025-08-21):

Easyeda project

dario-davi, 2025-08-21:
Ciao @mansellrace,

I just wanted to say thanks for the great work!
Any chance you could upload the PCB project to EasyEDA (https://easyeda.com/)? It would be super useful.

Thank you for your time!

EDIT: I mean PCB layout

mansellrace, 2025-08-25:
Hi Dario,
I have decided that the PCB design is not part of what is available open source, I hope you understand. I love sharing and exchanging projects, but my work (both hardware and software) has already been copied for commercial purposes, and in some cases the original project was not even mentioned.
I can also provide you with just the PCB or a kit to assemble. If you're interested, please contact me at mansellrace@gmail.com.

dario-davi, 2025-08-25:
Can I write you in Italian?
For what I know, Comelit has the most of its market in Italy

mansellrace, 2025-08-25:
Si, certamente, sono anche io italiano!

Closed 2025-08-25.

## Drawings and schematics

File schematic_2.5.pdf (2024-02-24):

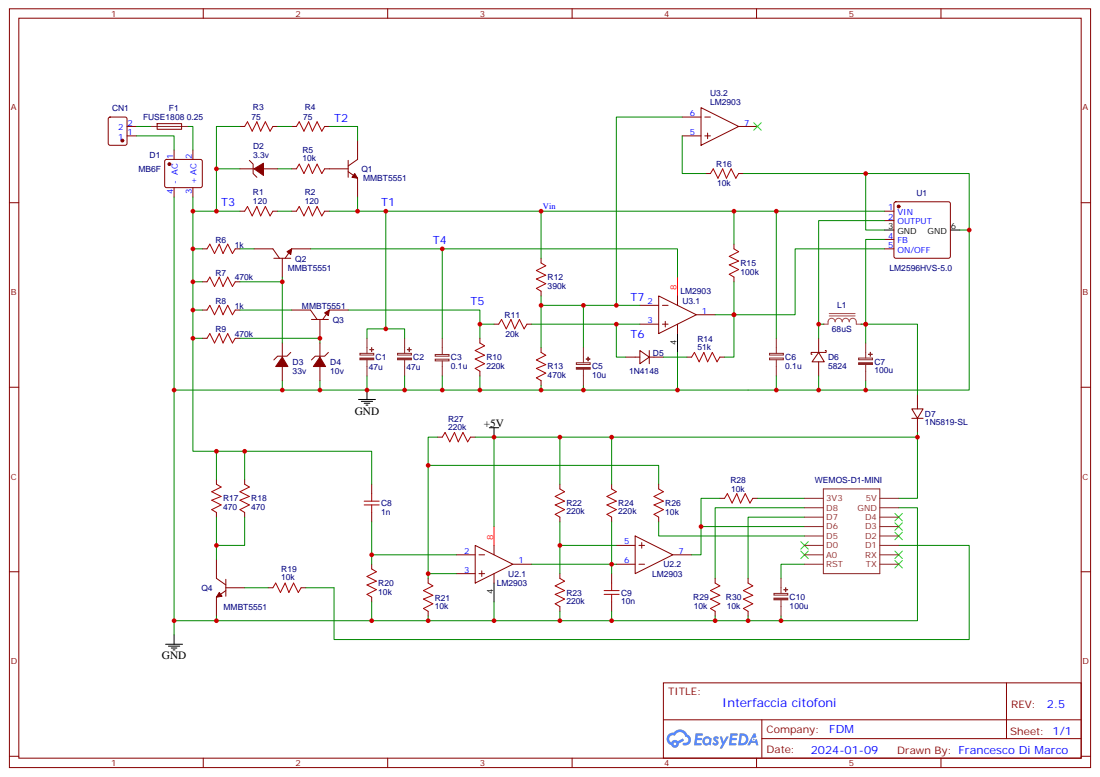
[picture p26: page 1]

Drawn By: Francesco Di Marco

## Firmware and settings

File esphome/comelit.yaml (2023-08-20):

esphome:
  name: comelit
  friendly_name: comelit
  includes:
    - comelit.h

esp8266:
  board: d1_mini    

# Enable logging
logger:
  #level: VERY_VERBOSE

ota:
  password: "----------------incolla qui la tua ota password---------------------"

wifi:
  ssid: !secret wifi_ssid
  password: !secret wifi_password
  ap:
    ssid: "Comelit Fallback Hotspot"
    password: "comelit"

captive_portal:
api:
  encryption:
    key: "----------------incolla qui la tua encription key---------------------"
  services:

    - service: invia_codice
      variables:
        comando: int
        indirizzo: int
      then:
        - remote_transmitter.transmit_raw:
            carrier_frequency: 25kHz
            code: !lambda return comelit_encode(indirizzo, comando);
        - homeassistant.service:
            service: logbook.log
            data:
              name: "Citofono:"
              entity_id: "binary_sensor.comelit_stato"
            data_template:
              message: "Inviato comando personalizzato {{ com }}, indirizzo {{ ind }}"
            variables:
              com: 'return comando;'
              ind: 'return indirizzo;'

    - service: apri_portone_esterno
      then:
        - remote_transmitter.transmit_raw:
            carrier_frequency: 25kHz
            code: !lambda return comelit_encode(1, 16);
        - homeassistant.service:
            service: logbook.log
            data:
              name: "Citofono:"
              entity_id: "binary_sensor.comelit_stato"
              message: "aperto portone esterno tramite domotica"


    - service: apri_portone_interno
      then:
        - remote_transmitter.transmit_raw:
            carrier_frequency: 25kHz
            code: !lambda return comelit_encode(1, 29);
        - homeassistant.service:
            service: logbook.log
            data:
              name: "Citofono:"
              entity_id: "binary_sensor.comelit_stato"
              message: "aperto portone interno tramite domotica"

    - service: apri_portoni
      then:
        - remote_transmitter.transmit_raw:
            carrier_frequency: 25kHz
            code: !lambda return comelit_encode(1, 16);
        - delay: 100ms
        - remote_transmitter.transmit_raw:
            carrier_frequency: 25kHz
            code: !lambda return comelit_encode(1, 29);
        - homeassistant.service:
            service: logbook.log
            data:
              name: "Citofono:"
              entity_id: "binary_sensor.comelit_stato"
              message: "aperti entrambi portoni tramite domotica"


globals:
  - id: codice
    type: int
    restore_value: no
    initial_value: '0'
  - id: indirizzo
    type: int
    restore_value: no
    initial_value: '0'
  - id: descrizione
    type: std::string

binary_sensor:
  - platform: status
    id: stato
    name: "stato"
    icon: mdi:doorbell

remote_transmitter:
  pin: D1
  carrier_duty_percent: 50%

remote_receiver:
  pin:
    number: D6
    inverted: false
  #dump: raw
  idle: 10ms
  filter: 250us
  buffer_size: 3k
  on_raw:
    then:
      - lambda: |-
          id(codice) = 0;
          id(indirizzo) = 0;
          ESP_LOGV("DEBUG", "RICEVUTO CODICE RAW DI LUNGHEZZA %u", size(x));
          char message[18];
          int bits = 0;
          if (size(x) == 38) {
            for (auto it = x.begin() + 1; it != x.end() -1; it+=2) {
              if (-*it < 2500 && -*it > 1000)
              {
                message[bits] = 0;
                bits += 1;
              }
              else if (-*it < 6200 && -*it > 3500)
              {
                message[bits] = 1;
                bits += 1;
              }
              if (bits == 18) {
                int sum = 0;
                int checksum = 0;
                for (int i = 0; i < 14; i++)
                {
                  if (message[i] == 1) sum++;
                }
                checksum = (message[17] * 8) + (message[16] * 4) + (message[15] * 2) + message[14];
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

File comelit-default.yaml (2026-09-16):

# Comelit intercom - Home Assistant interface
# https://github.com/mansellrace/comelit-esphome
#
# This is the configuration your device shipped with. Everything below is yours
# to change: rename the entities, delete the ones you do not use, add as many
# binary sensors and buttons as your installation needs.
#
# The options of the comelit_intercom component are documented here:
# https://github.com/mansellrace/comelit-esphome/blob/main/components/README.md

esphome:
  name: comelit-default
  friendly_name: Comelit
  comment: "Use this page to see the commands received from the bus"

esp8266:
  board: d1_mini
  restore_from_flash: true
  
preferences:
  flash_write_interval: 0s
  
logger:

# homeassistant_services is required: the component fires events through the
# Home Assistant API.
api:
  homeassistant_services: true

ota:
  - platform: esphome
  - platform: web_server

# Wi-Fi credentials are the ones you entered in the captive portal when you
# first set the device up, and they are kept in flash. If you prefer to have
# them in this file, add ssid and password here.
wifi:
  ap:
    ap_timeout: 10s
  min_auth_mode: WPA2

captive_portal:

web_server:
  version: 3

# refresh is explicit on purpose. Without it the github:// clone is cached for a
# whole day, so a device adopted right after a push validates against the previous
# state of the repo and fails on anything newly added.
external_components:
  - source: github://mansellrace/comelit-esphome
    refresh: 2min

comelit_intercom:
  hw_version: "2.6"

# The address your intercom answers to. You set it from Home Assistant, and the
# entities below pick it up straight away -- no recompiling needed.
# If you would rather hard-code the address, delete this number and write the
# plain value in the entities instead.
number:
  - platform: template
    id: comelit_address
    name: "Intercom address"
    icon: mdi:numeric
    optimistic: true
    restore_value: true
    initial_value: 1
    min_value: 1
    max_value: 255
    step: 1
    mode: box

# Turns on when someone calls your intercom (command 50 is the default).
# Add more of these to react to other commands, for example a door being opened.
binary_sensor:
  - platform: comelit_intercom
    name: "Incoming call"
    address: !lambda 'return (uint16_t) id(comelit_address).state;'

# What the device comment above points at: the last command seen on the bus,
# written as C<command>_A<address>. It goes back to empty after 10 seconds.
text_sensor:
  - platform: comelit_intercom
    name: "Last command"
    auto_clear: 0s

# Fires on every command addressed to your intercom, with the command number as
# the event type. Unlike the binary sensor it fires again when the very same
# command is received twice in a row.
# event:
#   - platform: comelit_intercom
#     name: "Intercom event"
#     address: !lambda 'return (uint16_t) id(comelit_address).state;'

# Command 16 opens the main door on most installations. Command 29 is the
# secondary door or a generic actuator. Chained sends need a 200ms delay
# between them.
button:
  - platform: template
    name: Open Door
    on_press:
      - comelit_intercom.send:
          command: 16
          address: 1

  - platform: template
    name: Open Secondary Door
    on_press:
      - comelit_intercom.send:
          command: 19
          address: 1
      - delay: 200ms
      - comelit_intercom.send:
          command: 16
          address: 1

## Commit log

2024-07-07 v 2.6
    Add support for 2.6 board
    Fix support to simplebus 1 board
    [comelit_intercom.cpp]
2024-11-20 3D box update
    [box comelit v2.stl, comelit-box.stl, comelit-top.stl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]
2024-12-28 Aggiunti doppi comandi di controllo pin
2025-06-22 Rename 3d_box/box comelit v2.stl to 3d_box/old_version/box comelit v2.stl
    [box comelit v2.stl]
2025-06-22 Rename 3d_box/top comelit v2.stl to 3d_box/old_version/top comelit v2.stl
    [top comelit v2.stl]
2025-06-22 new version of 3d box
    [Comelit box v3.stl, Comelit top v3.stl]
2026-10-01 Add ack option to binary sensor to acknowledge received commands
2026-10-01 Drop both edges of filtered glitches, recognize weaker ACK
    [comelit_intercom.cpp]
2026-10-01 Require idle to be longer than filter
